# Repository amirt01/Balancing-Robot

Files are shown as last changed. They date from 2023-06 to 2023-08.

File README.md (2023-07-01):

# Balancing-Robot
This is a personal project where I am designing, building, and programming a robot that can balance on two wheels. Some goals I have for this robot are:
1. Simple Balance - if the robot is pushed, correct the disturbance and regain balance
2. Position Lock - once the robot regains its balance, return to the original location
3. Joystick Control - be able to control the robot's movement using a joystick via a phone app

I learned about stepper motors and stepper motor control, Complementary Filters, and complex PID control during this project.
## Libraries
[Arduino_LSM6DS3](https://reference.arduino.cc/reference/en/libraries/arduino_lsm6ds3/)

[WiFiNINA](https://www.arduino.cc/reference/en/libraries/wifinina/)

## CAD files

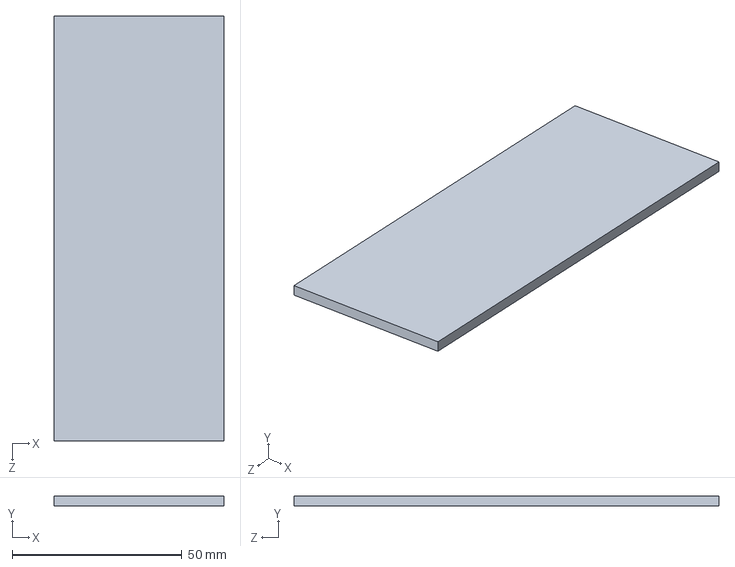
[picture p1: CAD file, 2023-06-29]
CAD/plate.SLDPRT
50.0 x 3.00 x 125.0 mm

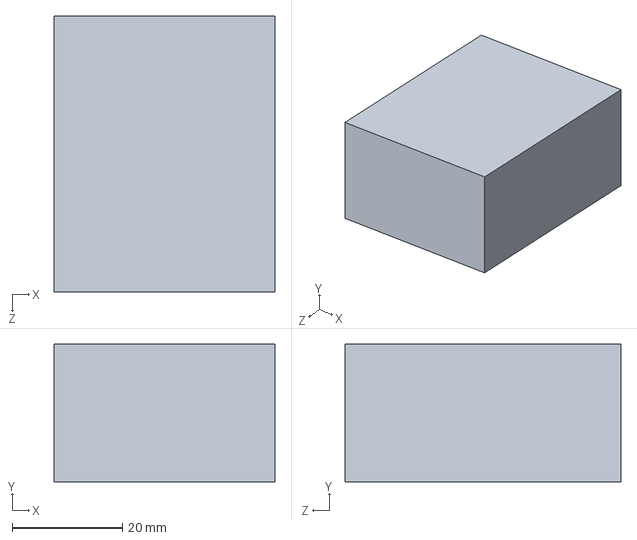
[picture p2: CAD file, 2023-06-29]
CAD/battery.SLDPRT
40.0 x 25.0 x 50.0 mm

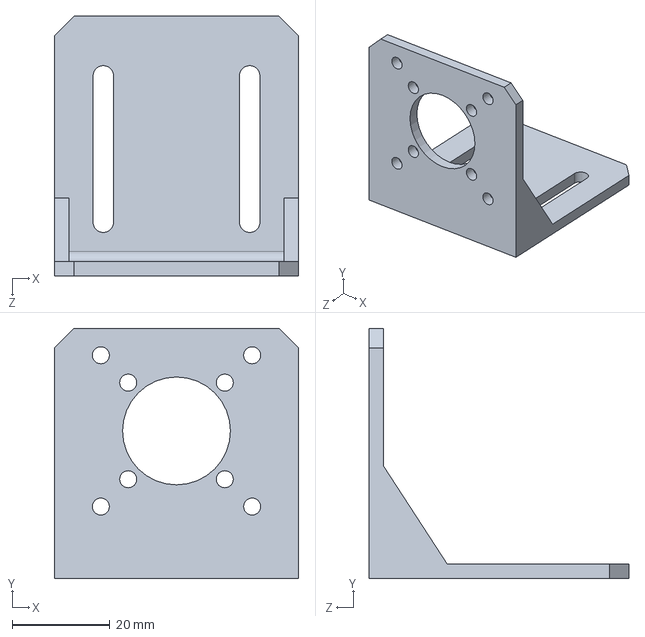
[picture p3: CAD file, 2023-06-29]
CAD/bracket.SLDPRT
50.0 x 51.2 x 53.2 mm

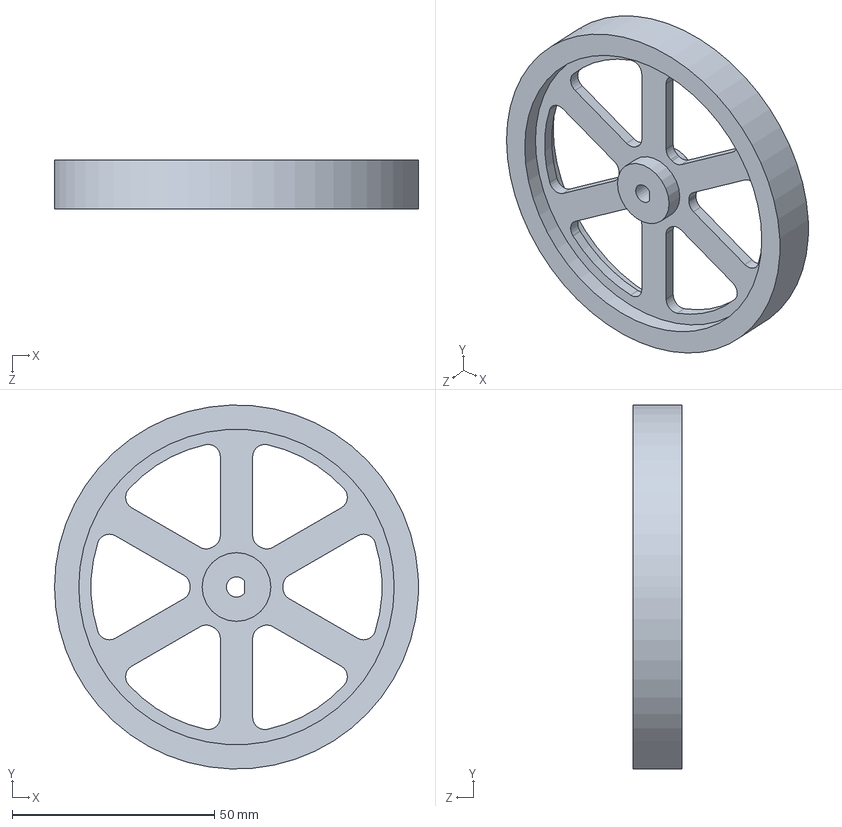
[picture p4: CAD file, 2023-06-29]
CAD/wheel.SLDPRT
90.0 x 90.0 x 12.0 mm

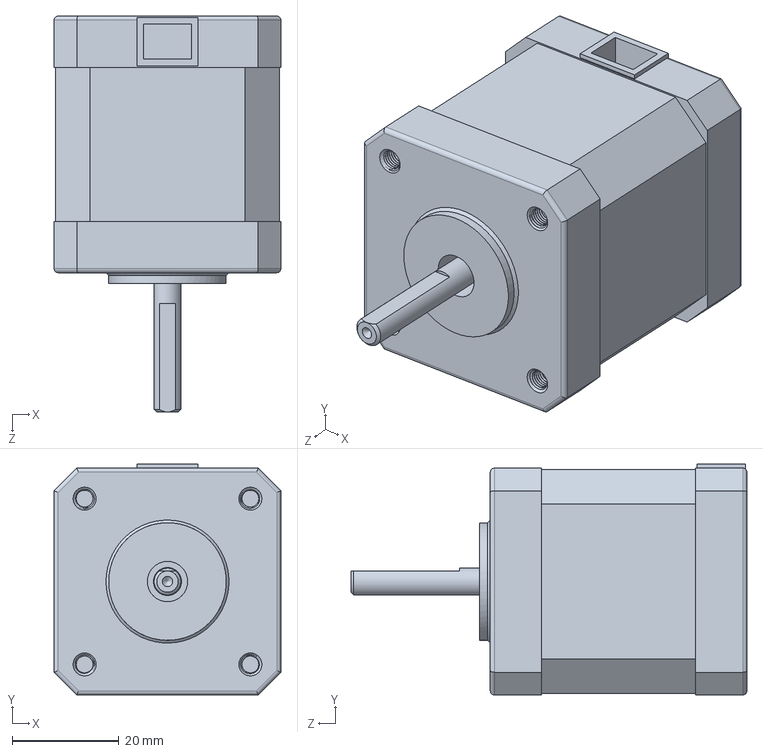
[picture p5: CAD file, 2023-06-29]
CAD/6627T91_Stepper Motor.SLDPRT
42.4 x 43.2 x 74.0 mm

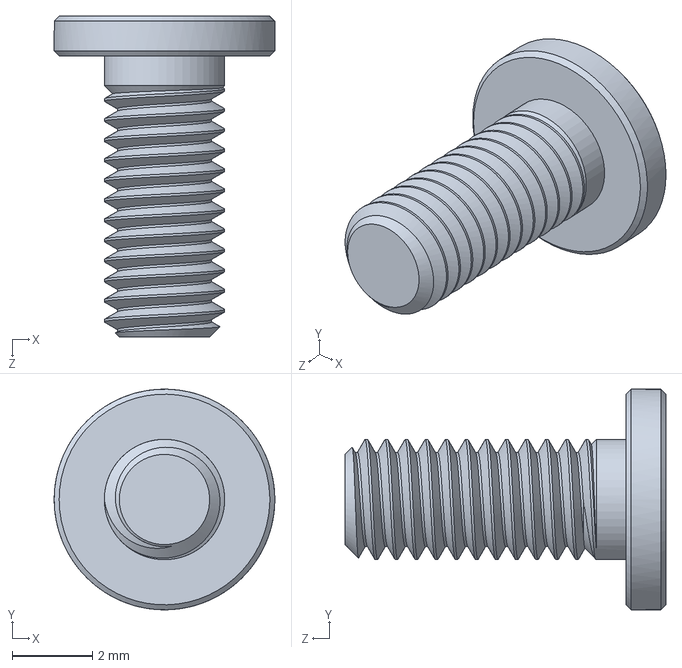
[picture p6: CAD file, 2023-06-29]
CAD/90358A117_Ultra-Low-Profile Socket Head Screw.SLDPRT
5.50 x 5.50 x 8.00 mm

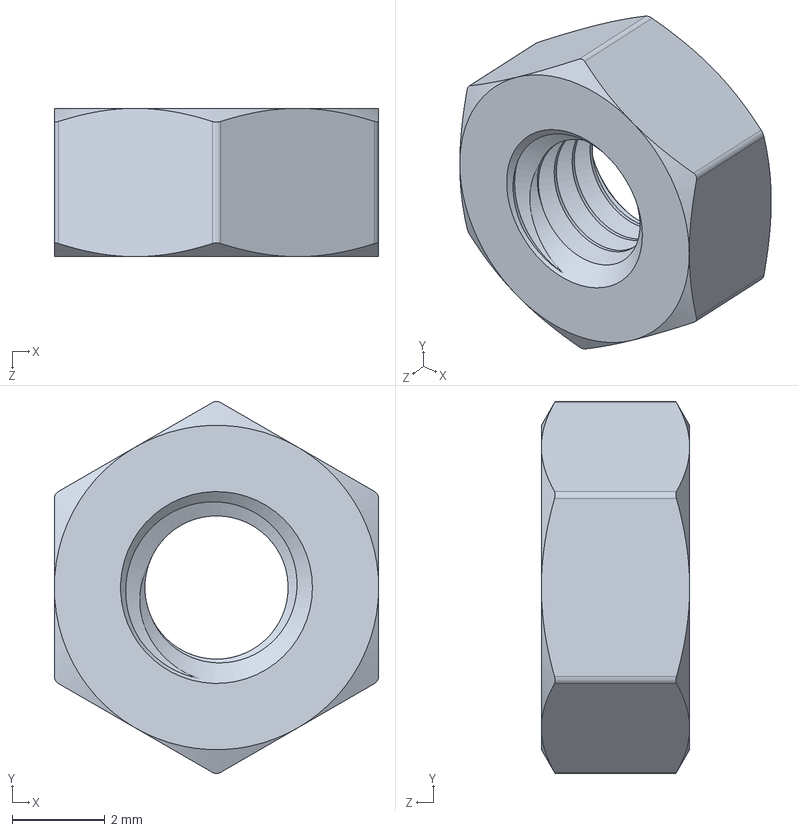
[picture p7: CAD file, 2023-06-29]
CAD/90592A011_Steel Hex Nut.SLDPRT
7.00 x 8.03 x 3.20 mm

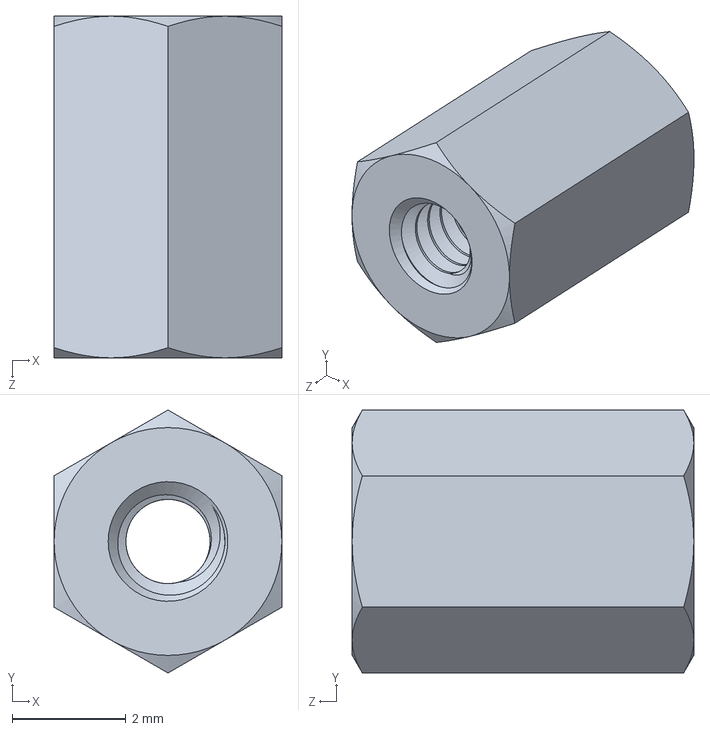
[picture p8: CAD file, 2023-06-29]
CAD/1319N21_Nylon 6 6 Plastic Coupling Nut.SLDPRT
4.00 x 4.62 x 6.00 mm

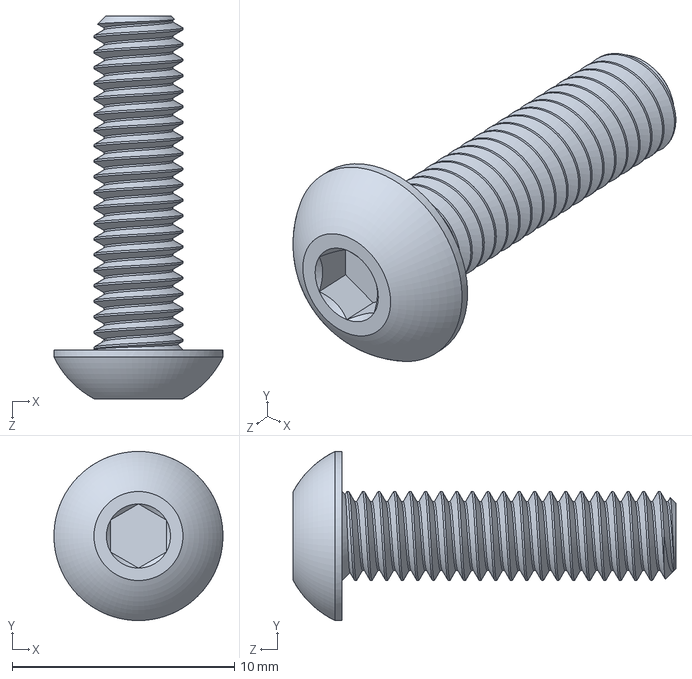
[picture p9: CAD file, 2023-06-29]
CAD/92095A125_Button Head Hex Drive Screw.SLDPRT
7.60 x 7.60 x 17.2 mm

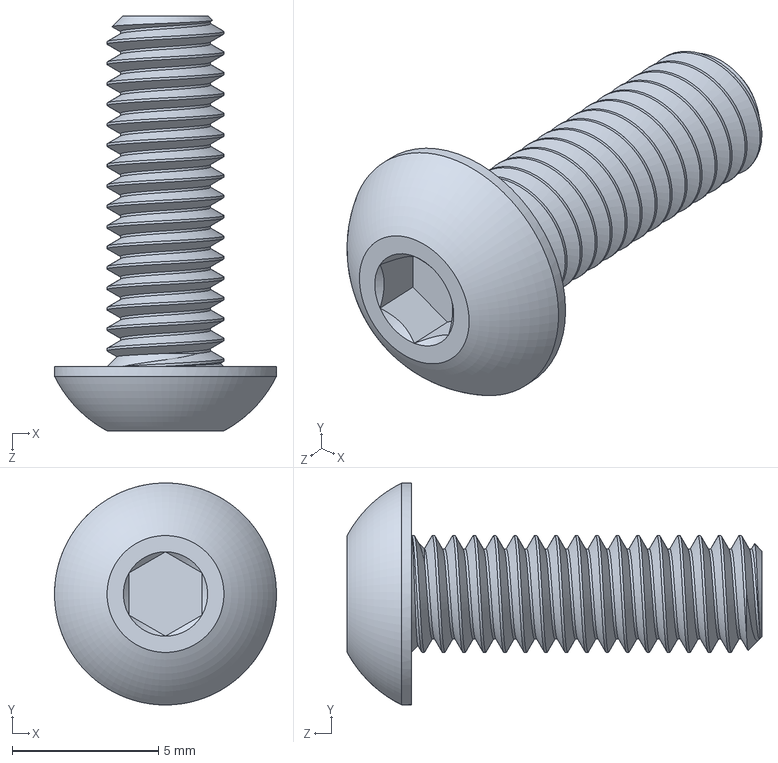
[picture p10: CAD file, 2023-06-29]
CAD/92095A192_Button Head Hex Drive Screw.SLDPRT
7.60 x 7.60 x 14.2 mm

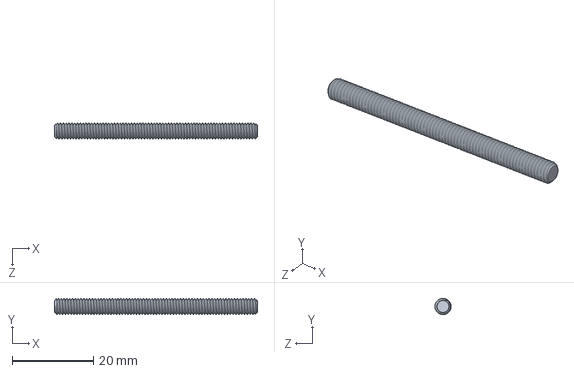
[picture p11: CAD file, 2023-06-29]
CAD/94595A238_Low-Strength Zinc-Plated Steel Threaded Rod.SLDPRT
50.0 x 4.00 x 4.00 mm

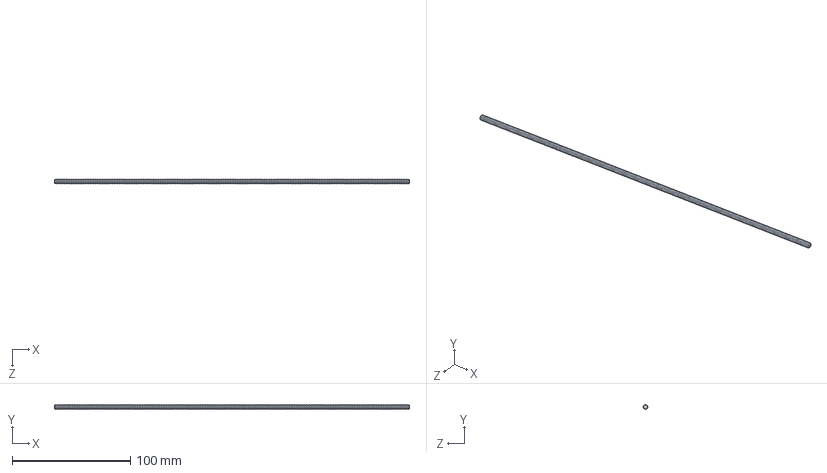
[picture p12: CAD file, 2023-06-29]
CAD/94595A216_Low-Strength Zinc-Plated Steel Threaded Rod.SLDPRT
300.0 x 4.00 x 4.00 mm

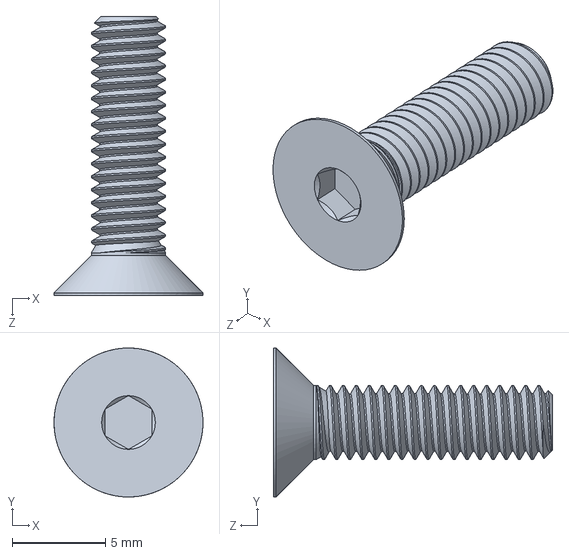
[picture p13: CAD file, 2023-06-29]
CAD/92125A104_18-8 Stainless Steel Hex Drive Flat Head Screw.SLDPRT
8.00 x 8.00 x 15.0 mm

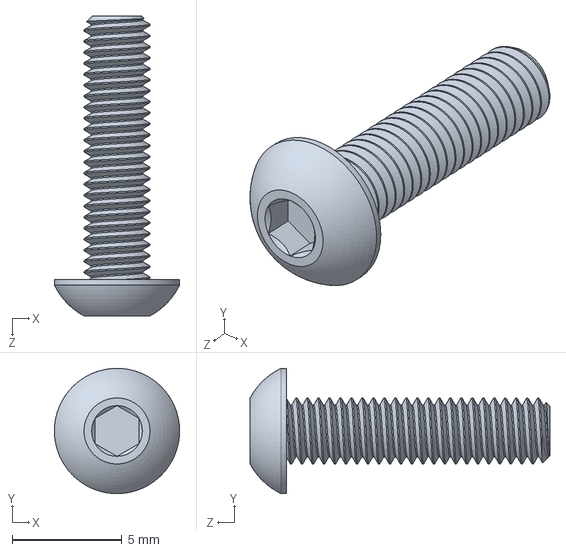
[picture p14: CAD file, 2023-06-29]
CAD/94500A264_316 Stainless Steel Button Head Hex Drive Screws.SLDPRT
5.70 x 5.70 x 13.7 mm

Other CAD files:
CAD/90592A090_Steel Hex Nut.SLDPRT
CAD/98689A113_General Purpose 18-8 Stainless Steel Washer.SLDPRT
CAD/2726N61_Medium Density Fiberboard Sheet.SLDPRT

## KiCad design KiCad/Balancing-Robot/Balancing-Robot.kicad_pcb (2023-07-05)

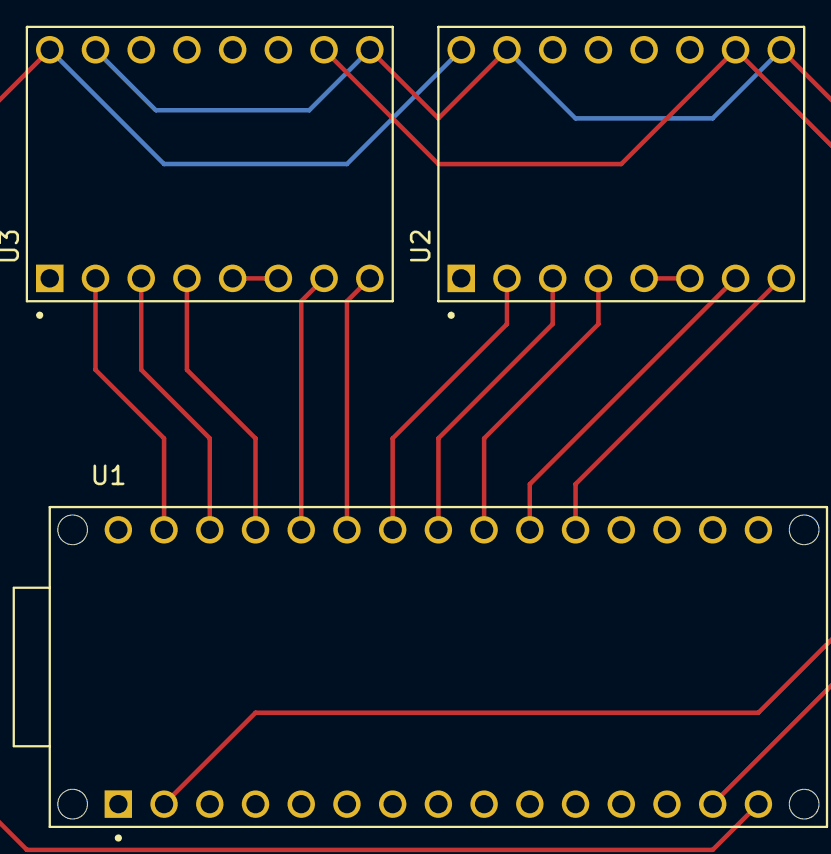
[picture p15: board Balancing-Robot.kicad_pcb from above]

Board: 2 copper layers, 3 parts (0 on the bottom side), 15 nets.

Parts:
U1: ABX00053; MODULE_ABX00053
U2, U3: A4988_STEPPER_MOTOR_DRIVER_CARRIER; MODULE_A4988_STEPPER_MOTOR_DRIVER_CARRIER

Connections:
/D2: U1.20 (D2/GPIO25), U2.8 (DIR)
/D3: U1.21 (D3/GPIO15), U2.7 (STEP)
/D4: U1.22 (D4/GPIO26), U2.4 (MS3)
/D5: U1.23 (D5/GPIO17), U2.3 (MS2)
/D6: U1.24 (D6/GPIO18), U2.2 (MS1)
/D7: U1.25 (D7/GPIO19), U3.8 (DIR)
/D8: U1.26 (D8/GPIO20), U3.7 (STEP)
/D9: U1.27 (D9/GPIO21), U3.4 (MS3)
/D10: U1.28 (D10/GPIO5), U3.3 (MS2)
/D11: U1.29 (D11/GPIO7/COPI), U3.2 (MS1)
GND: U1.14 (GND), U1.19 (GND), U2.9 (GND), U2.15 (GND), U3.9 (GND), U3.15 (GND)
unnamed: U2.5 (~RESET), U2.6 (~SLEEP)
unnamed: U3.5 (~RESET), U3.6 (~SLEEP)
VCC: U1.15 (VIN), U2.16 (VMOT), U3.16 (VMOT)
VDD: U1.2 (+3V3), U2.10 (VDD), U3.10 (VDD)

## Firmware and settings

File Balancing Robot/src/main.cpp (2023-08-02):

#include <Arduino.h>
#include <Arduino_LSM6DS3.h>
#include "DRV8825.h"
#include "StatusLED.h"
#include "IMU_Data.h"

#define DEBUG false

#define MOTOR_STEPS 200

#define DIR_PIN_1 2
#define STEP_PIN_1 3
#define MODE0_1 6
#define MODE1_1 5
#define MODE2_1 4

#define DIR_PIN_2 7
#define STEP_PIN_2 8
#define MODE0_2 11
#define MODE1_2 10
#define MODE2_2 9

DRV8825 stepper1(MOTOR_STEPS, DIR_PIN_1, STEP_PIN_1,
                 MODE0_1, MODE1_1, MODE2_1);

DRV8825 stepper2(MOTOR_STEPS, DIR_PIN_2, STEP_PIN_2,
                 MODE0_2, MODE1_2, MODE2_2);

static const double TARGET_ANGLE = 3.5;

StatusLED LED;

void InitIMU();
void InitMotors();

IMU_Data ReadIMU();
double CalculateAngle(const IMU_Data&);
double ComputePID(const double&);
void UpdateMotors(const float&, const double&);

void setup() {
#if DEBUG
    Serial.begin(115200);
    delay(5000);
    Serial.println("Serial Initialized!");
#endif

    InitIMU();
    InitMotors();
    LED.InitLED();

#if DEBUG
    Serial.println("Acceleration in g's | Gyroscope in degrees/second");
    Serial.println("aX\taY\taZ | gX\tgY\tgZ");
#endif
}

void loop() {
    const IMU_Data data = ReadIMU();

    const double calculatedAngle = CalculateAngle(data);

    const double angleError = TARGET_ANGLE - calculatedAngle;
    const double speed = ComputePID(angleError);

#if DEBUG
    Serial.print(calculatedAngle);
    Serial.print('\t');
    Serial.print(speed);
    Serial.print('\t');
#endif

    UpdateMotors(abs(speed), angleError);
    stepper1.nextAction();
    stepper2.nextAction();

    LED.UpdateLED();
}

void InitMotors() {
    stepper1.begin();
    stepper2.begin();
    stepper1.enable();
    stepper2.enable();

#if DEBUG
    Serial.println("Motors Initialized!");
#endif
}

void InitIMU() {
    if (!IMU.begin()) {
#if DEBUG
        Serial.println("Failed to initialize IMU!");
#endif
    } else {
#if DEBUG
        Serial.println("IMU Initialized!");
#endif
    }

#if DEBUG
    Serial.print("Gyroscope sample rate = ");
    Serial.print(IMU.gyroscopeSampleRate());
    Serial.println(" Hz");
    Serial.print("Accelerometer sample rate = ");
    Serial.print(IMU.accelerationSampleRate());
    Serial.println(" Hz");
    Serial.println();
#endif
}

IMU_Data ReadIMU() {
    static IMU_Data data{};
    if (IMU.accelerationAvailable()) {
        IMU.readAcceleration(data.ax, data.ay, data.az);
#if DEBUG
        Serial.print(data.ax);
        Serial.print('\t');
        Serial.print(data.ay);
        Serial.print('\t');
        Serial.print(data.az);
        Serial.print('\t');
#endif
    }

    if (IMU.gyroscopeAvailable()) {
        IMU.readGyroscope(data.gx, data.gy, data.gz);
#if DEBUG
        Serial.print(data.gx);
        Serial.print('\t');
        Serial.print(data.gy);
        Serial.print('\t');
        Serial.print(data.gz);
#endif
    }

    return data;
}

double CalculateAngle(const IMU_Data& data) {
    // Loop Time Calculation
    const uint32_t currTime = millis();
    static uint32_t prevTime = currTime;  // declare and initially assign prevTime to currTime
    const uint32_t dt = currTime - prevTime;
    prevTime = currTime;  // update prevTime to currTime

    // Angle Variables
    static double calculatedAngle = 0;

    // Two Angle Calculation Methods
    const double accAngle = atan2(data.ay, data.az) * RAD_TO_DEG;
    const double gyroAngle = calculatedAngle + (data.gx + 0.12) * dt / 1000;  // -0.12 is steady state error

    // Complementary Filter Factors
    static const double tau = 0.5;  // effective filter time (0.5s)
    double a = tau / (tau + (double)dt / 1000.0);

    // Complementary Filtered Angle (high pass filter on gyro; low pass filter on acc)
    calculatedAngle = a * gyroAngle + (1-a) * accAngle;

#if DEBUG
    static uint64_t printTime = millis() + 100;
    if (millis() > printTime) {
        printTime += 100;
        Serial.print(accAngle);
        Serial.print('\t');
        Serial.print(gyroAngle);
        Serial.print('\t');
        Serial.print(calculatedAngle);
        Serial.print('\t');
    }
#endif

    return calculatedAngle;
}

double ComputePID(const double& angleError) {
    // Loop Time Calculation
    uint64_t currTime = millis();
    static uint64_t prevTime = 0;  // declare and initially assign prevTime to currTime
    uint64_t dt = currTime - prevTime;
    double dt_s = (double)dt / 1000.0;
    prevTime = currTime;  // update prevTime to currTime

    // PID constants
    static const double Kp = 10.0;
    static const double Ki = 1.0;
    static const double Kd = 0.1;

    // Variables for PID control
    static double previousError = 0.0;
    static double integral = 0.0;

    // Proportional term
    double proportional = Kp * angleError;

    // Integral term
    integral += Ki * angleError * dt_s;
    integral = constrain(integral, -200, 200);

    // Derivative term
    double derivative = Kd * (angleError - previousError) / dt_s;
    previousError = angleError;

    // Compute the PID output
    double output = proportional + integral + derivative;

#if DEBUG
    static uint64_t printTime = millis() + 100;
    if (millis() > printTime) {
        printTime += 100;
        Serial.print(proportional);
        Serial.print('\t');
        Serial.print(integral);
        Serial.print('\t');
        Serial.print(derivative);
        Serial.print('\t');
        Serial.println(output);
    }
#endif

    return output;
}

void UpdateMotors(const float& speed, const double& angleError) {
    stepper1.setRPM(speed);
    stepper2.setRPM(speed);

    stepper1.startRotate(-angleError);
    stepper2.startRotate(angleError);
}

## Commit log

2023-06-29 CAD Initial Commit
    [1319N21_Nylon 6 6 Plastic Coupling Nut.SLDPRT, 2726N61_Medium Density Fiberboard Sheet.SLDPRT, 6627T91_Stepper Motor.SLDPRT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]
2023-07-01 working IMU control
2023-07-01 PID tuning
2023-07-07 circuit board updates
2023-07-31 revert to different strategy
    [main.cpp]
